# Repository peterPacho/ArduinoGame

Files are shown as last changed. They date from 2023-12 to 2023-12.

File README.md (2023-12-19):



## Description
"Retro Brick Game" inspired Arduino game console with multiplayer support. 

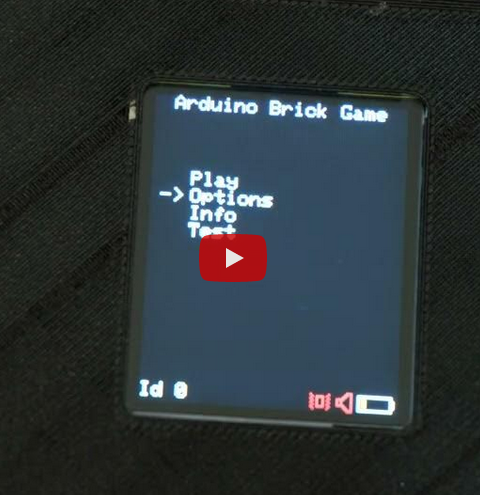
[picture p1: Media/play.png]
[](https://www.youtube.com/watch?v=qxOgujPc98Q)

[Link to the video](https://www.youtube.com/watch?v=qxOgujPc98Q)

Made as a project for University Of Illinois CS 362 class, Fall 2023.

## Parts list (for a single console):
- Arduino Nano
- 128x160 LCD Display
- NRF24L0+ module
- 18650 3.7 Li-on battery
- Li-on charger/power bank module
- DC to DC converter (to convert too-low and varying battery voltage to stable 5V to power Arduino)
- Passive buzzer
- Vibration motor
- 2x 3.3V voltage regulators AMS1117-3.3 (NRF24L0+ module requires 3.3V and vibration motor requires 3V, they are separated to hopefully reduce any noise/interference from the DC motor)
- 2x mosfets (to act as switch for buzzer and DC motor)
- 7x PCB buttons
- slide switch / power switch
- and other supporting components like resistors, capacitors, wires, etc.

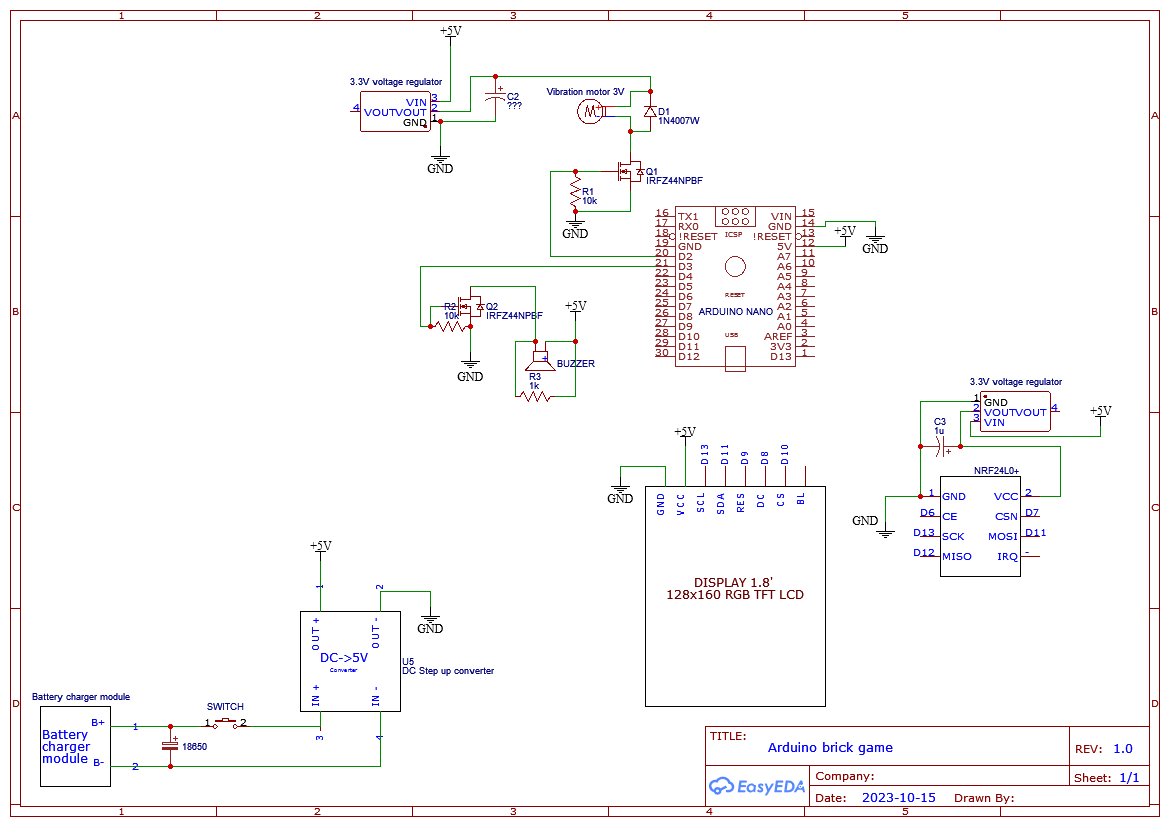
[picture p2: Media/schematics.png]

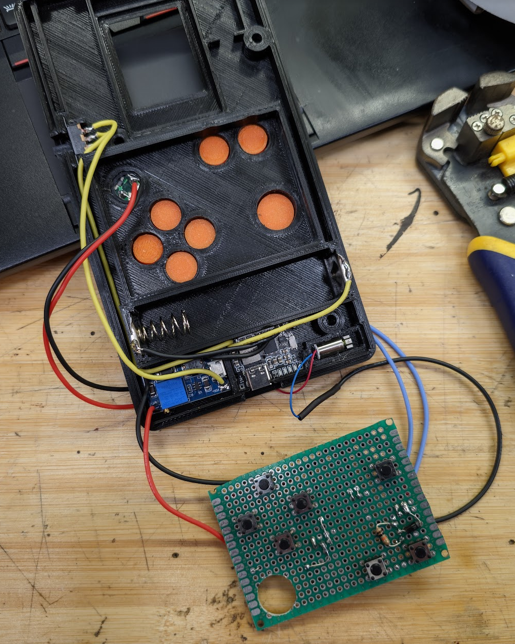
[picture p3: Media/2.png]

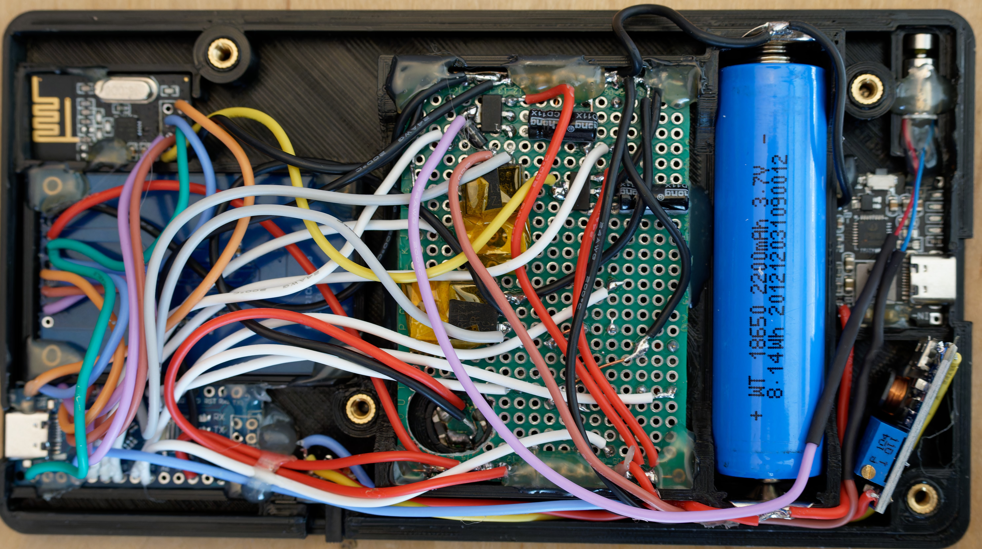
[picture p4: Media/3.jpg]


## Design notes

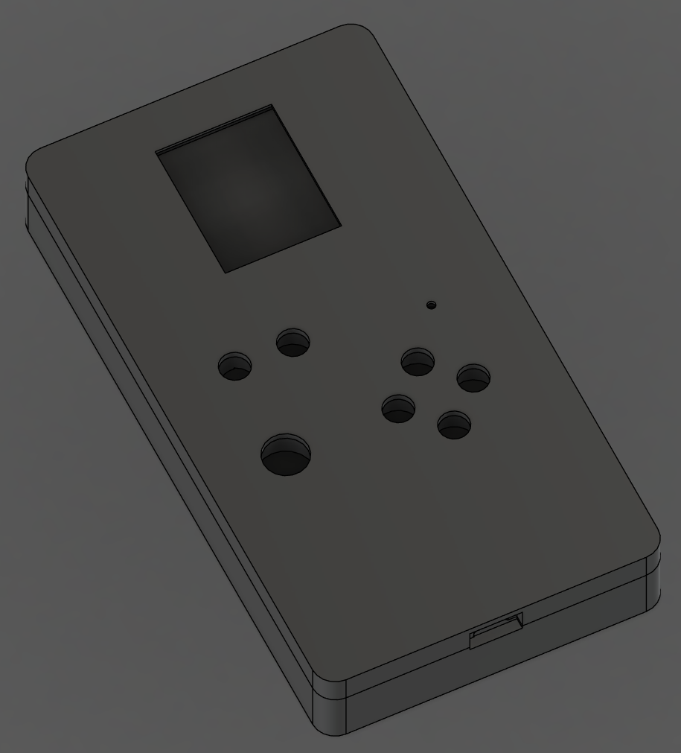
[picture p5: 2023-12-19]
Fusion360/Screenshot 2023-11-01 191738.png

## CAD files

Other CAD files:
Fusion360/Arduino Brick Game v10.f3d

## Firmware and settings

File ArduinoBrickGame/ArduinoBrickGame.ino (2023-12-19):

/*
	List of references/libraries:
	- ST775 display driver - https://github.com/adafruit/Adafruit-ST7735-Library
	- Two way communication - https://www.hackster.io/lightthedreams/nrf24l01-for-communication-1-way-and-2-way-80e65c
*/

#include <SPI.h>
#include <Adafruit_ST7735.h> // https://github.com/adafruit/Adafruit-ST7735-Library library for ST7735
#include <RF24.h>			 // https://github.com/nRF24/RF24 - RF24 by TMRh20
#include <avr/eeprom.h>
#include "ButtonEvent.h"
#include "MainMenu.h"
#include "Pong.h"
#include "Settings.h"

/*
	Display has 128x160 resolution.

	Pin-out notes for NANO:
		- Both display and NRF24L0+ use SPI interface which means
			they should share those pins: MOSI - D11, MISO - D12, SCK - D13

			Display -> Arduino:
				- GND -> GND
				- VCC -> 5V
				- SCL -> D13 (SCK pin, Serial Clock)
				- SDA -> D11 (MOSI - Master out slave in)
				- RES -> D9
				- DC -> D8
				- CS -> D10
			NRF24L0+ -> Arduino:
			-----------------
			1 2             /   1 - GND                 2 - VCC (3.3V !!!)
			3 4             \   3 - CE (Chip enable)    4 - CSN - Chip Select Not
			5 6             /   5 - SCK (Serial Clock)  6 - MOSI (Master Out Slave In)
			7 8             \   7 - MISO (master in)    8 - IRQ - Interrupt pin
			-----------------
				- GND -> GND
				- VCC -> 3.3V !!!
				- CE -> D6
				- CSN -> D7
				- SCK -> D13
				- MOSI -> D11
				- MISO -> D12

	If uploading first time / using new arduino, go to settings and set the console ID.
*/
#define DISPLAY_CS 10
#define DISPLAY_RST 9
#define DISPLAY_DC 8
#define nRF24_CSN 7
#define nRF24_CE 6

#define BUZZER 3
#define VIBR 5
const byte BATTERY = A0; // connected to battery positive to measure battery voltage

const uint8_t radioAddress[][6] = {"1Node", "2Node"};

Adafruit_ST7735 display = Adafruit_ST7735(DISPLAY_CS, DISPLAY_DC, DISPLAY_RST);

// radio setup from https://github.com/nRF24/RF24/blob/master/examples/GettingStarted/GettingStarted.ino
RF24 radio(nRF24_CE, nRF24_CSN);

/*
	This function should be called continuously in the loop without any parameters.
	If vibration is required, pass a parameter of how long it should vibrate.

	So there must be a call to any loop that might take a long time, or
	vibrations might be stuck ON.

	I'm assuming there will be no instance when we want vibrations to be longer than 2 seconds.
	If passed with vibr > 2000 it means "shut it off"
*/
void vibrate(unsigned long newDuration = __LONG_MAX__, byte newPwm = 255)
{
	static unsigned long startedAt = 0;
	static unsigned long duration = 0;

	// if passed with parameter and vibrations are not disabled
	if (newDuration != __LONG_MAX__ && newDuration <= 2000 && SETTINGS.vibrations)
	{
		duration = newDuration;
		analogWrite(VIBR, newPwm);
		startedAt = millis();
		return;
	}
	else if (newDuration != __LONG_MAX__ && newDuration > 2000)
	{
		duration = 0;
		startedAt = 0;
	}

	// if without, check if vibration should be turned off
	if (millis() - startedAt > duration)
	{
		digitalWrite(VIBR, 0);
	}
}

void toneHelper(unsigned int freq, unsigned int duration)
{
	if (SETTINGS.sound)
		tone(BUZZER, freq, duration);
	else
		noTone(BUZZER);
}

void setup(void)
{
	/*
		Load settings from EEPROM
	*/
	loadSettings();

	// Serial.begin(9600);
	pinMode(BUZZER, OUTPUT);
	pinMode(VIBR, OUTPUT);

	display.initR(INITR_GREENTAB);
	display.fillScreen(0);
	display.setCursor(0, 0);

	// initialize the transceiver on the SPI bus
	if (!radio.begin())
	{
		print(F("Radio fail"), 0, 0, COLOR_RED);

		while (1)
		{
		}
	}

	// radio.setPALevel( RF24_PA_LOW ); // RF24_PA_MAX is default.
	radio.setPALevel(RF24_PA_HIGH);

	// set the TX address of the RX node into the TX pipe
	radio.openWritingPipe(radioAddress[SETTINGS.id]); // always uses pipe 0

	// set the RX address of the TX node into a RX pipe
	radio.openReadingPipe(1, radioAddress[!SETTINGS.id]); // using pipe 1

	radio.powerDown();
}

void loop()
{
	radio.powerDown();
	vibrate(10000);
	digitalWrite(VIBR, 0);
	noTone(BUZZER);
	delay(100);

	int returnedFromMenu = mainMenu();

	if (returnedFromMenu == 0)
	{
		display.fillScreen(COLOR_BLACK);
		Pong pong;
		if (pong.pong_menu())
			pong.pong_play();
	}
}

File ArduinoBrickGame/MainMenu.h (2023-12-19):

#pragma once
#include <SPI.h>
#include <Adafruit_ST7735.h> // https://github.com/adafruit/Adafruit-ST7735-Library library for ST7735
#include <RF24.h>			 // https://github.com/nRF24/RF24 - RF24 by TMRh20
#include "ButtonEvent.h"
#include "Settings.h"

/*
	If this is set to 1, test menu is completely disabled.
	(all code for test menu is removed before compiling)

	Last time I checked, disabling it saves almost 6.5 Kb of memory
*/
#define DISABLE_TEST_MENU 0
#define BUZZER 3
#define VIBR 5

// all objects defined in main .ino file that will also be used here
extern Adafruit_ST7735 display;
extern RF24 radio;
extern const byte BATTERY;

/*
	All string constants for menu options.
	Holding them in this way uses PROGMEM rather than RAM
	from https://playground.arduino.cc/Main/PROGMEM/

	First position is "Title" that will be on the top of the screen,
	rest are the options that user can select.
*/

// If making changes to main menu, search for "CHANGE ME IF MAKING CHANGES TO MAIN MENU" and change code there
const char _menu_main_0[] PROGMEM = "Arduino Brick Game";
const char _menu_main_1[] PROGMEM = "Play";
const char _menu_main_2[] PROGMEM = "Options";
const char _menu_main_3[] PROGMEM = "Info";
#if DISABLE_TEST_MENU == 0
const char _menu_main_4[] PROGMEM = "Test";
const char *const menuMain[] PROGMEM = {_menu_main_0, _menu_main_1, _menu_main_2, _menu_main_3, _menu_main_4};
#else
const char *const menuMain[] PROGMEM = {_menu_main_0, _menu_main_1, _menu_main_2, _menu_main_3};
#endif

const char _menu_play_0[] PROGMEM = "Games";
const char _menu_play_1[] PROGMEM = "Pong";
const char *const menuPlay[] PROGMEM = {_menu_play_0, _menu_play_1};

#if DISABLE_TEST_MENU == 0
const char _menu_test_0[] PROGMEM = "Test menu";
const char _menu_test_1[] PROGMEM = "Buzzer";
const char _menu_test_2[] PROGMEM = "Vibrator";
const char _menu_test_3[] PROGMEM = "Wireless";
const char _menu_test_4[] PROGMEM = "Buttons";
const char _menu_test_5[] PROGMEM = "Colors";
const char _menu_test_6[] PROGMEM = "Colors 2";
const char *const menuTest[] PROGMEM = {_menu_test_0, _menu_test_1, _menu_test_2, _menu_test_3, _menu_test_4, _menu_test_5, _menu_test_6};
#endif

const char _menu_options_0[] PROGMEM = "Options";
const char _menu_options_1[] PROGMEM = "Vibrations: ";
const char _menu_options_2[] PROGMEM = "Sound: ";
const char _menu_options_21[] PROGMEM = "Save to EEPROM";
const char _menu_options_3[] PROGMEM = "Set console ID 0";
const char _menu_options_4[] PROGMEM = "Set console ID 1";
const char _menu_options_5[] PROGMEM = "Reset to default";
const char *const menuOptions[] PROGMEM = {_menu_options_0, _menu_options_1, _menu_options_2, _menu_options_21, _menu_options_3, _menu_options_4, _menu_options_5};

const int menuOptionX = 20, menuOptionY = 40, menuOptionHeight = 9;

// bitmaps generated on http://javl.github.io/image2cpp/
//  'battery', 18x10px
const unsigned char bitmapBattery[] PROGMEM = {
	0x00, 0x00, 0x00, 0xff, 0xff, 0x80, 0x80, 0x00, 0x80, 0x80, 0x00, 0xc0, 0x80, 0x00, 0xc0, 0x80,
	0x00, 0xc0, 0x80, 0x00, 0xc0, 0x80, 0x00, 0x80, 0xff, 0xff, 0x80, 0x00, 0x00, 0x00};
// 'speaker', 8x10px
const unsigned char bitmapSpeaker[] PROGMEM = {
	0x07, 0x0d, 0x19, 0xf1, 0xa1, 0xa1, 0xf1, 0x19, 0x0d, 0x07};
// 'vibr', 10x10px
const unsigned char bitmapVibr[] PROGMEM = {
	0x00, 0x00, 0x80, 0x40, 0x5e, 0x80, 0x92, 0x40, 0x52, 0x80, 0x92, 0x40, 0x52, 0x80, 0x9e, 0x40,
	0x40, 0x80, 0x00, 0x00};

int playMenu();
void testMenu(), infoMenu(), optionsMenu(), drawInfoPanel();

/*
	To make printing the string from the progmem easier.
	Can be used like:
		printProgmem(&(menuMain[0]));

	x - optional parameter, where to set the cursor for printing
	y - optional parameter, where to set the cursor for printing
*/
void printProgmem(const char *const *string, int x = -1, int y = -1)
{
	char *buffer = new char[strlen(*string) + 1];
	strcpy_P(buffer, (char *)pgm_read_ptr(string));

	if (x >= 0 && y >= 0)
	{
		display.setCursor(x, y);
	}

	display.print(buffer);
	delete buffer;
}

/*
	Another print helper function. Works with F macro.
*/
template <typename type>
void print(type string, int x = -1, int y = -1, uint16_t color = -1)
{
	if (x >= 0 && y >= 0)
		display.setCursor(x, y);

	if (color != -1)
		display.setTextColor(color);
	else
		display.setTextColor(COLOR_WHITE);

	display.print(string);
}
void printOnOff(bool on, int y)
{
	if (on)
		print(F("ON"), 100, y, COLOR_GREEN);
	else
		print(F("OFF"), 100, y, COLOR_RED);
}
/*
	Prints the given char array so the text in centered
*/
void printCentered(char *str, int y)
{
	display.setCursor(128 / 2 - 6 * strlen(str) / 2, y);
	display.print(str);
}

/*
	Used to draw menu from the PROGMEM char arrays.
	Use the drawMenu macro to print.
	Use like: drawMenu(menuMain);
*/
#define drawMenu(progmemArr) _drawMenu(progmemArr, sizeof(progmemArr) / sizeof(char *))
void _drawMenu(const char *const *menu, const int menuSize)
{
	display.fillScreen(0);
	drawInfoPanel();
	printProgmem(&(menu[0]), 10, 0);

	for (int i = 1; i < menuSize; i++)
	{
		printProgmem(&(menu[i]), menuOptionX, menuOptionY + menuOptionHeight * (i - 1));
	}
}

/*
	Used to draw the arrow cursor that points to the menu option.
	If calling first time for the given menu, pass with (>=0, maxPosition) arguments.
	Then call it without any parameters.
*/
byte getMenuSelector(int reset = -1, int maxPosition = -1)
{
	static byte menuSelector = 0;	  // position of the cursor
	static byte menuSelectorLast = 0; // what was the last position? used to detect when to update the screen
	static byte maxMenuSelector = 0;

	if (reset >= 0)
	{
		menuSelector = reset;
		menuSelectorLast = -1; // enforce update
	}

	if (maxPosition >= 0)
	{
		maxMenuSelector = maxPosition;
	}

	if (menuSelector != menuSelectorLast)
	{
		// check the selector bounds:
		if (menuSelector < 0)
			menuSelector = maxMenuSelector;
		if (menuSelector > maxMenuSelector)
			menuSelector = 0;

		// clear the previous position of the cursor
		print(F("->"), menuOptionX - 15, menuOptionY + menuOptionHeight * menuSelectorLast, ST7735_BLACK);

		// print new cursor position
		print(F("->"), menuOptionX - 15, menuOptionY + menuOptionHeight * menuSelector);

		menuSelectorLast = menuSelector;
	}

	if (button.up.state())
	{
		if (menuSelector == 0)
			menuSelector = maxMenuSelector;
		else
			menuSelector--;
	}

	if (button.down.state())
		menuSelector++;

	return menuSelector;
}
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
